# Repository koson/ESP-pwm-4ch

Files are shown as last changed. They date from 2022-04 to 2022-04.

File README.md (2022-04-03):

# ESP-pwm-4ch

ESP8266/ESP32 based board with 4x PWM output channels.

This board is designed to be driven by an Olimex ESP32-POE, ESP32-POE-ISO or Wemos D1 Mini modules running Tasmota. If you want to use the ethernet interface present on the Olimex modules you will need to compile your own Tasmota binaries enabling the corresponding features.

The design considers that the board will be mounted on a PCB DIN rail holder offered by the Brazilian manufacturer Metaltex. Check [here](https://www.metaltex.com.br/produtos/componentes/suportes/sp7-suporte-para-montagem-de-placa-de-circuito-impresso-em-trilho-din) for details.

Heatsinks are included in the design as I wasn't sure about how much power the MOSFETs would dissipate. The first tests were performed using zero ohm resistors between the drivers and the transistors. A 5A load was applied and the transistor showed no noticeable temperature elevation. In version 2 I replaced the zero ohm resistors for 22 ohm to avoid damages to the drivers, and this setup hasn't yet been tested. Given the very low switching frequency and small loads I suppose the heatsinks are still not needed.

Expect some flicker when driving LEDs with the ESP8266. It gets much more stable when using the hardware PWMs of the ESP32.

There is a preferred version of this board with 8x PWM channels and individual pins for powering groups of two outputs, what enables driving the full 5A per channel. Click [here](https://github.com/thermseekr/ESP-pwm-8ch) to check it.

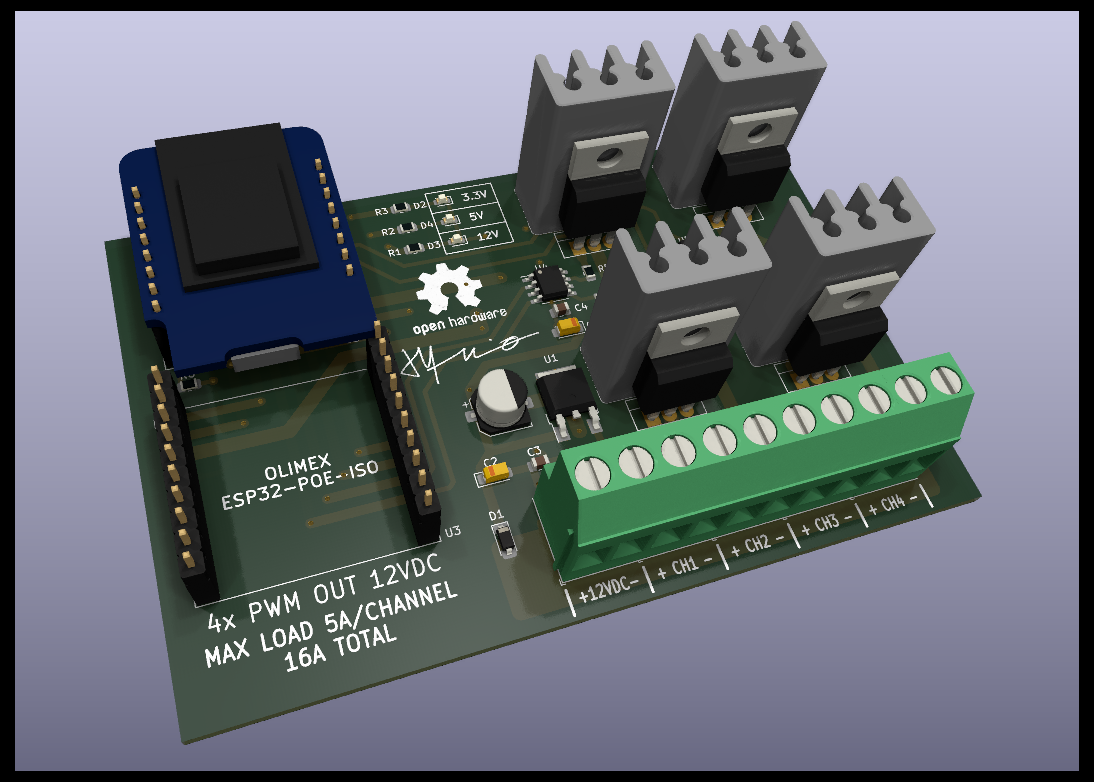
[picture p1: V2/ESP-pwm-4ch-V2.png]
ESP-pwm-4ch


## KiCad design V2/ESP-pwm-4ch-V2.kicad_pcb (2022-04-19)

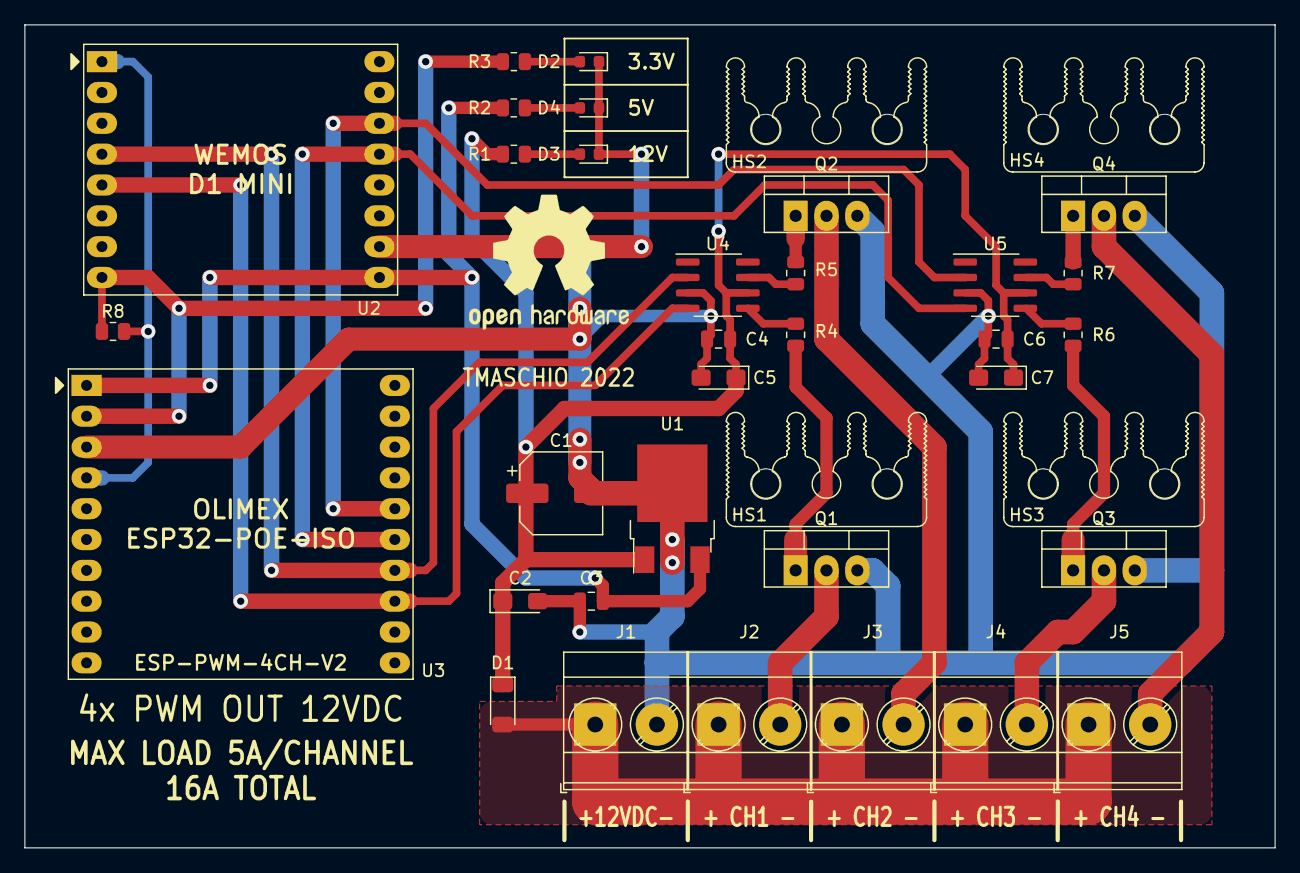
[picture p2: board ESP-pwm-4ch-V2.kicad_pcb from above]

Board: 2 copper layers, 103.0 x 67.8 mm, 37 parts (0 on the bottom side), 25 nets.

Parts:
C1: 47uF/35V/6,3x5,4; CP_Elec_6.3x5.4
C2: 0,33uF/35V; CP_EIA-3216-18_Kemet-A_Pad1.58x1.35mm_HandSolder
C3, C4, C6: 0,1uF/50V/0805; C_0805_2012Metric
C5, C7: 1uF 35V; CP_EIA-3216-18_Kemet-A_Pad1.58x1.35mm_HandSolder
D1: SM4007PL/SOD-123; D_SOD-123
D2, D3, D4: GREEN/0603; LED_0603_1608Metric
HS1, HS2, HS3, HS4: Heatsink_16x10x25mm_2xFixationM3
J1: 12VDC; TerminalBlock_Phoenix_MKDS-3-2-5.08_1x02_P5.08mm_Horizontal
J2: OUT1; TerminalBlock_Phoenix_MKDS-3-2-5.08_1x02_P5.08mm_Horizontal
J3: OUT2; TerminalBlock_Phoenix_MKDS-3-2-5.08_1x02_P5.08mm_Horizontal
J4: OUT3; TerminalBlock_Phoenix_MKDS-3-2-5.08_1x02_P5.08mm_Horizontal
J5: OUT4; TerminalBlock_Phoenix_MKDS-3-2-5.08_1x02_P5.08mm_Horizontal
Q1, Q2, Q3, Q4: IRLB8721PBF; TO-220-3_Vertical
R1: 2k2/0,125W/0805; R_0805_2012Metric
R2: 680R/0,125W/0805; R_0805_2012Metric
R3: 270R/0,125W/0805; R_0805_2012Metric
R4, R5, R6, R7: 22R/0,125W/0805; R_0805_2012Metric
R8: 4k7/0,125W/0805; R_0805_2012Metric
U1: L78M05; TO-252-2
U2: WeMos_D1_mini; WEMOS_D1_mini_light_pads
U3: Olimex_ESP32-POE; Olimex_ESP32-POE_Pads
U4, U5: IR4427; SOIC-8_3.9x4.9mm_P1.27mm

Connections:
+3V3: R3.1, R8.1, U2.8 (3V3), U3.2 (3V3)
+5V: C3.1, R2.1, U1.3 (OUT), U2.9 (5V), U3.1 (5V)
+12V: D1.2 (A), J1.1, J2.1, J3.1, J4.1, J5.1
+12VA: C1.1, C2.1, C4.1, C5.1, C6.1, C7.1, D1.1 (K), R1.1, U1.1 (IN), U4.6 (VS), U5.6 (VS)
GNDREF: C1.2, C2.2, C3.2, C4.2, C5.2, C6.2, C7.2, D2.1 (K), D3.1 (K), D4.1 (K), J1.2, Q1.3 (S), Q2.3 (S), Q3.3 (S), Q4.3 (S), U1.2 (GND), U2.10 (GND), U3.3 (GND), U4.3 (GND), U5.3 (GND)
unnamed: D2.2 (A), R3.2
unnamed: D3.2 (A), R1.2
unnamed: D4.2 (A), R2.2
unnamed: J2.2, Q1.2 (D)
unnamed: J3.2, Q2.2 (D)
unnamed: J4.2, Q3.2 (D)
unnamed: J5.2, Q4.2 (D)
unnamed: Q1.1 (G), R4.1
unnamed: Q2.1 (G), R5.1
unnamed: Q3.1 (G), R6.1
unnamed: Q4.1 (G), R7.1
unnamed: R4.2, U4.5 (OUTB)
unnamed: R5.2, U4.7 (OUTA)
unnamed: R6.2, U5.5 (OUTB)
unnamed: R7.2, U5.7 (OUTA)
unnamed: R8.2, U2.1 (~RST), U3.4 (ESP_EN)
unnamed: U2.4 (SCK/D5), U3.14 (GPIO16\I2C-SCL), U4.2 (INA)
unnamed: U2.5 (MISO/D6), U3.13 (GPIO15\HS2_CMD), U4.4 (INB)
unnamed: U2.13 (SDA/D2), U3.15 (GPIO32), U5.4 (INB)
unnamed: U2.14 (SCL/D1), U3.16 (GPIO33), U5.2 (INA)

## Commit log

2022-02-02 Initial upload
    [ESP-pwm_4ch-V1-B_Cu.gbr, ESP-pwm_4ch-V1-B_Mask.gbr, ESP-pwm_4ch-V1-Edge_Cuts.gbr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]
2022-02-05 V2 upload
    [ESP-pwm_4ch-V2.kicad_pcb, ESP-pwm_4ch-V2.sch]
2022-02-17 kicad version update
    [ESP-pwm_4ch-V1.kicad_pcb, ESP-pwm_4ch-V1.kicad_sch]
2022-02-28 Cleanup after migration to Kicad 6
    [ESP-pwm_4ch-V1.kicad_pcb, ESP-pwm_4ch-V1.sch, ESP-pwm_4ch-V2.kicad_pcb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]
2022-03-06 kicad update
2022-03-07 V2 development
    [ESP-pwm_4ch-V2.kicad_pcb, ESP-pwm_4ch-V2.kicad_sch]
2022-03-29 work in progress
    [ESP-pwm_4ch-V2.kicad_pcb, ESP-pwm_4ch-V2.kicad_sch]
2022-04-01 Gate resistor from 0R to 22R
    [ESP-pwm_4ch-V2.kicad_sch]
2022-04-01 General improvement to the routing
    [ESP-pwm_4ch-V2.kicad_pcb]
2022-04-01 Upload board images
2022-04-01 Reset pulled up to +3.3V
    [ESP-pwm_4ch-V2.kicad_pcb, ESP-pwm_4ch-V2.kicad_sch]
2022-04-01 Tweaking footprints
    [ESP-pwm_4ch-V2.kicad_pcb, ESP-pwm_4ch-V2.kicad_sch]
2022-04-01 PCB tweaks
    [ESP-pwm_4ch-V2.kicad_pcb]
2022-04-03 rename files to new schema
    [ESP-pwm-4ch-V1.kicad_pcb, ESP-pwm-4ch-V1.kicad_sch]
